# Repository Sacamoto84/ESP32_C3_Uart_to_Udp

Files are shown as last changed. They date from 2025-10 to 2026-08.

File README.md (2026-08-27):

# ESP32 UART to TCP Bridge

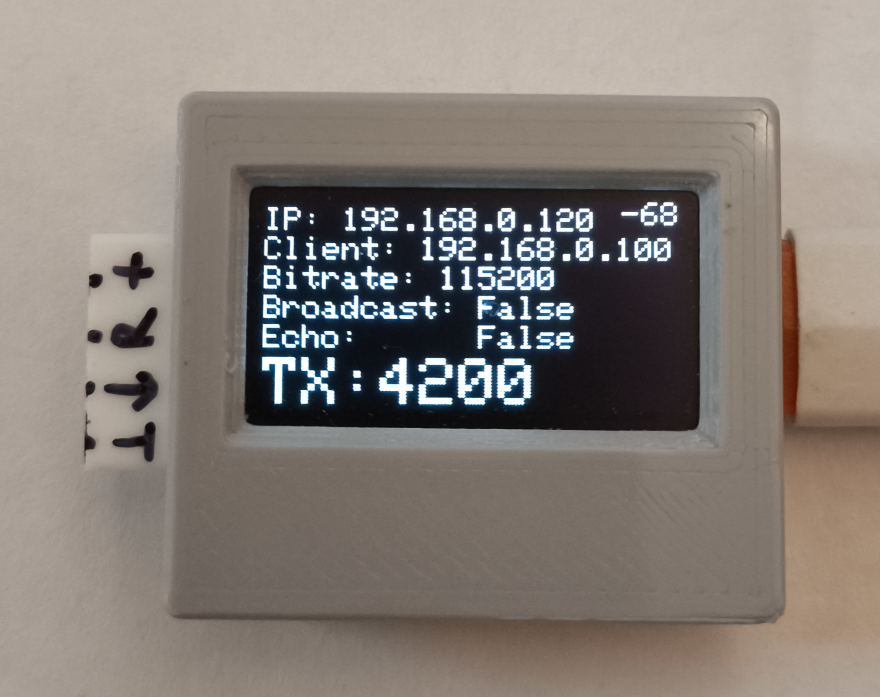
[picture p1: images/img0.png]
ESP32 UART to TCP Bridge


Прошивка превращает ESP32 в сетевой мост `UART -> TCP`, чтобы Android-приложение `TerminalM3` могло подключаться к устройству как TCP-клиент, получать поток данных из UART и показывать его в терминале.

Актуальная схема работы такая:

- ESP32 поднимает `TCP server` на порту `8888` для потока `UART -> Android`
- ESP32 поднимает `TCP server` на порту `8900` для команд `Android -> ESP32 SimpleCLI`
- Android сам подключается к ESP32 как `TCP client`
- `UDP` только для двух служебных задач:
  - heartbeat `ping/pong` на порту `8888`
  - внешний экран OLED framebuffer на порту `82`, если эта функция включена (`1024` байта для 128x64, `360` байт для 72x40)

## Что умеет проект

- Передавать поток данных из UART в TCP-соединение.
- Держать отдельную очередь `UART -> TCP`, чтобы медленная сеть не блокировала чтение UART.
- Автоматически использовать `PSRAM` под сетевую очередь, если она есть.
- Поднимать web-портал настроек на ESP32.
- Работать с `DHCP` или `static IP`.
- Публиковать сервисы через `mDNS`.
- Поддерживать `OTA`-обновление.
- Показывать локальный статус на OLED, если сборка с экраном.
- Работать в режиме точки доступа `AP ESP32`, если подключение к Wi-Fi не удалось.

## Актуальная архитектура

### 1. Передача данных UART

Основной транспорт:

```text
UART -> очередь -> TCP server:8888 -> Android TCP client
Android TCP client -> TCP server:8900 -> SimpleCLI
```

### 2. Heartbeat между Android и ESP32

Для контроля соединения используется отдельный `UDP heartbeat`.

- Android шлет на ESP32 строку вида:

```text
tm3 hb ping seq=123
```

- ESP32 отвечает обратно на IP и порт отправителя:

```text
tm3 hb pong seq=123
```

Текущие параметры по коду:

- UDP порт heartbeat: `8888`
- Android считает соединение пропавшим, если `pong` не приходит примерно `3` секунды
- в Android heartbeat сейчас запускается отдельным клиентом и используется как индикатор живого соединения

### 3. Внешний экран по UDP

Если сборка идет с экраном и в настройках включен внешний экран, ESP32 слушает UDP-порт `82` и принимает framebuffer для OLED.

Это отдельный режим и он не связан с передачей UART в Android.

## Сетевые порты и сервисы

### Порты

- `TCP 8888` - основной сервер UART -> Android
- `TCP 8900` - прием команд Android -> `SimpleCLI`
- `UDP 8888` - heartbeat `ping/pong`
- `UDP 82` - внешний экран OLED framebuffer, если включен
- `TCP 80` - web-портал настроек
- `TCP 3232` - OTA

### mDNS

ESP32 публикует:

- `http.tcp` на порту `80`

Имя хоста задается через `PROJECT_OTA_HOSTNAME`, либо берется по умолчанию:

- `esp32-c3-uart`
- `esp32-s2-uart`

## Поддерживаемые платы

## ESP32-C3

Environment в `PlatformIO`:

```text
esp32-c3-devkitm-1
esp32-c3-devkitm-1_ota
```

Пины:

- `UART TX = GPIO21`
- `UART RX = GPIO20`
- `AP_MODE_PIN = GPIO8`
- `RESET_PULSE_PIN = GPIO9`
- `LED = GPIO8`

OLED `SSD1306` подключен по `SPI`:

```text
GPIO6  -> MOSI
GPIO4  -> CLK
GPIO3  -> DC
GPIO1  -> CS
GPIO2  -> RESET
```

## ESP32-C3 OLED 72x40

Для плат `ESP32-C3 0.42 OLED` / `01Space ESP32C3 0.42 OLED` добавлены окружения:

```text
esp32-c3-oled-72x40
esp32-c3-oled-72x40_ota
```

Встроенный OLED — SSD1306-совместимый, `72x40`, I2C-адрес `0x3C`:

```text
SDA -> GPIO5
SCL -> GPIO6
```

Пины моста по умолчанию:

- `UART TX = GPIO21`
- `UART RX = GPIO20`
- `RESET_PULSE_PIN = GPIO10` (GPIO9 не используется, так как это BOOT)
- `LED = GPIO8`

Малый экран показывает тот же статус в компактном шрифте. В режиме внешнего экрана по UDP он ожидает framebuffer размером `360` байт (`72 * 40 / 8`). Для OTA укажите адрес платы при загрузке, например `platformio run -e esp32-c3-oled-72x40_ota -t upload --upload-port 192.168.1.50`.

## ESP32-S2 Mini

Environment в `PlatformIO`:

```text
lolin_s2_mini
lolin_s2_mini_ota
```

Пины:

- `UART TX = GPIO5`
- `UART RX = GPIO3`
- `RESET_PULSE_PIN = GPIO9`
- `LED = GPIO15`
- `BOOT_HIGH_PIN = GPIO36`
- `BOOT_LOW_PIN = GPIO38`

OLED `SSD1306` подключен по `I2C`:

```text
SDA   -> GPIO21
SCL   -> GPIO34
VCC   -> GPIO36
GND   -> GPIO38
ADDR  -> 0x3C
RESET -> -1
```

## Wi-Fi логика

Прошивка работает так:

- стартует в режиме `STA`
- при включенном `static IP` сначала пытается применить адрес, шлюз и маску
- мощность Wi-Fi берется из настроек
- если подключение не удалось, делает повторную попытку с мощностью `8.5 dBm`
- если снова не удалось, переключается в `AP` режим
- имя точки доступа fallback-режима: `AP ESP32`

Перед инициализацией Wi-Fi частота CPU понижается до `80 MHz`.

## Статусный светодиод

Встроенный LED платы используется как индикатор состояния. Управляется отдельной `FreeRTOS`-задачей с приоритетом выше `loopTask`, поэтому мигание не зависит от текущей работы главного цикла (обновление OLED, OTA и т.д.) и работает корректно даже на одноядерном `ESP32-S2`.

Команды приходят в задачу через очередь FreeRTOS, то есть вызов из любой пользовательской таски неблокирующий и потокобезопасный.

Состояния:

- `Off` — LED выключен (Wi-Fi не активен).
- `ConnectingToStation` — медленное мигание `~350 ms` (подключение к Wi-Fi).
- `AccessPoint` — быстрое мигание `~120 ms` (активирован fallback `AP ESP32`).
- `WaitingForClient` — LED выключен (Wi-Fi подключён, TCP-клиента нет).
- `ClientConnected` — ровно горит, пока клиент на связи. При активной передаче данных быстро мигает `~20 Hz` (как activity-LED у RJ-45), через `~120 ms` после последнего пакета возвращается в ровное свечение.

Таким образом по одному светодиоду видно:

- есть ли подключение к Wi-Fi,
- подключился ли клиент к TCP-серверу,
- идёт ли сейчас реальная передача данных.

Темп мигания активности и окно удержания настраиваются константами в `src/status_led.cpp` (`kActivityBlinkHalfMs`, `kActivityHoldMs`).

### Полярность и яркость

LED считается доступным всегда:

- `ESP32-C3` — RGB/NeoPixel на пине `8`
- `LOLIN S2 Mini` — обычный GPIO на пине `15`, по умолчанию **active HIGH**

В web-портале настраиваются включение LED, полярность `active LOW` и яркость `0..255`.
По умолчанию LED включён, яркость полная: `255`.

## Очередь UART -> TCP и PSRAM

Проект использует очередь между UART и TCP, чтобы сеть не тормозила прием данных из UART.

Один элемент очереди:

```cpp
struct NetworkTxChunk {
    uint16_t len;
    uint8_t data[NETWORK_TX_CHUNK_SIZE];
};
```

Текущее поведение:

- сначала проект пытается создать очередь в `PSRAM`
- если не получилось, пытается создать очередь во внутренней RAM
- если памяти не хватает, автоматически уменьшает длину очереди в 2 раза, пока не найдет рабочий вариант
- если очередь так и не создалась, TCP server все равно стартует, чтобы это было видно в диагностике

Текущие compile-time размеры:

- `PROJECT_NETWORK_TX_CHUNK_SIZE = 1460`

Стартовое значение TX-очереди для новой базы настроек:

- `64` чанка для `ESP32-C3`
- `256` чанков для `ESP32-S2 Mini`
- дальше размер TX-очереди меняется в web-портале и применяется после перезагрузки ESP32

Дополнительно:

- драйверный RX-буфер UART: по умолчанию `64 KB`, дальше меняется в web-портале
- локальный буфер чтения из UART: `NETWORK_TX_CHUNK_SIZE * 4`
- таймаут записи TCP: `3000 ms`

Если очередь переполняется, новые данные дропаются без краша прошивки, а в лог пишется счетчик потерь.

## Web-портал настроек

Портал настроек поднимается на ESP32 и позволяет менять:

- bitrate UART
- размер входного RX-буфера Serial/UART в KB
- SSID и пароль Wi-Fi
- включение `static IP`
- `static IP`, `gateway`, `subnet`
- `echo`
- мощность передатчика Wi-Fi
- включение встроенного LED, полярность `active LOW` и яркость
- яркость OLED, если экран есть
- включение внешнего экрана по UDP `82`, если экран есть
- перезагрузку ESP32
- аппаратный импульс сброса на внешнее устройство
- очистку базы настроек

В портале также показываются:

- текущий IP ESP32
- строка OTA вида `hostname.local:3232`
- состояние OTA auth
- режим транспорта: `TCP server`
- фактический размер очереди `UART -> TCP`

## OTA

Параметры по умолчанию:

- OTA порт: `3232`
- hostname для `ESP32-C3`: `esp32-c3-uart`
- hostname для `ESP32-S2 Mini`: `esp32-s2-uart`

Environment для OTA:

```text
esp32-c3-devkitm-1_ota
esp32-c3-oled-72x40_ota
lolin_s2_mini_ota
```

Примеры:

```bash
platformio run --environment esp32-c3-devkitm-1
platformio run --environment esp32-c3-devkitm-1_ota --target upload
platformio run --environment esp32-c3-oled-72x40
platformio run --environment esp32-c3-oled-72x40_ota --target upload --upload-port 192.168.1.50
platformio run --environment lolin_s2_mini
platformio run --environment lolin_s2_mini_ota --target upload
```

## Полезные build flags

### Без экрана SSD1306 128x64

```text
-DPROJECT_NO_SCREEN=1
```

### Размеры сетевых буферов

```text
-DPROJECT_NETWORK_TX_CHUNK_SIZE=1460
```

### Подробный лог UART hot path

Включать только для отладки, потому что заметно нагружает быстрый путь:

```text
-DPROJECT_UART_VERBOSE_LOG=1
```

### Ожидание Serial-монитора при старте

По умолчанию прошивка ждёт подключение Serial-монитора до `5000 ms`, чтобы ранние диагностические логи не терялись сразу после сброса.
Отключить ожидание или изменить таймаут можно флагом:

```text
-DPROJECT_BOOT_SERIAL_DELAY_MS=0
```

### OTA hostname и пароль

```text
-DPROJECT_OTA_HOSTNAME="my-esp32-bridge"
-DPROJECT_OTA_PASSWORD="change-me"
```

## Запуск с Android TerminalM3

- https://github.com/Sacamoto84/Android_TerminalM3

Android-приложение работает с этой прошивкой по такой схеме:

1. Android определяет IP ESP32 автоматически или берет его из ручной настройки.
2. Android открывает постоянное `TCP` соединение на `8888` для чтения UART.
3. Android шлет команды `SimpleCLI` в `TCP 8900` по схеме `connect -> send -> close`.
4. Параллельно Android шлет heartbeat `ping` по `UDP 8888`.
5. Если heartbeat пропадает, Android считает сервер потерянным, роняет TCP-сокет и пытается переподключиться.

Это позволяет отдельно контролировать жив ли сервер, даже если TCP еще не успел сам отвалиться по таймаутам ОС.

## Связанные документы

- [Корневой README проекта Android TerminalM3](../README.md)
- [README консольных виджетов Android](../app/src/main/java/com/example/terminalm3/console/README.md)
- [README библиотеки TimberWidget для Arduino/PlatformIO](../TimberWidget/README.md)

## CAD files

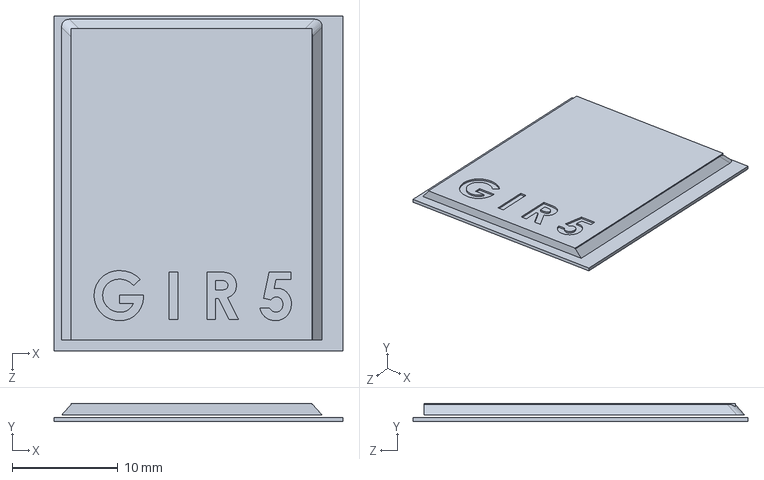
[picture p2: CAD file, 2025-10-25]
3d/крышка.SLDPRT
27.3 x 1.72 x 31.6 mm

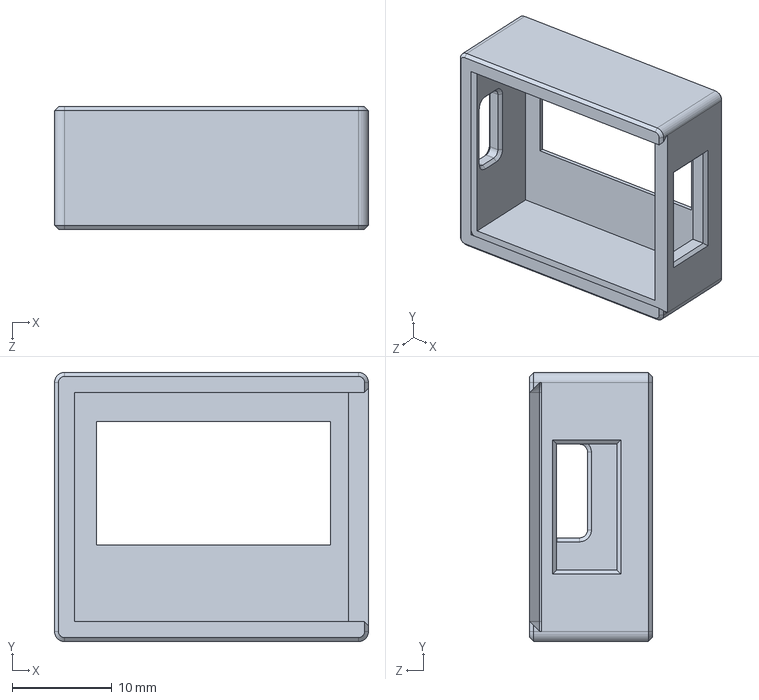
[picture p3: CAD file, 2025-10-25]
3d/низ.SLDPRT
31.5 x 27.0 x 12.3 mm

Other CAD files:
3d/крышка.STL
3d/низ.STL

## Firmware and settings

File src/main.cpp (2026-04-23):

#include "app_globals.h"

#include "display.h"
#include "network_bridge.h"

#include <GTimer.h>

// Держит главный цикл коротким: обслуживает OTA, внутренности настроек/БД,
// heartbeat-ответы и активный режим отображения.
void loop()
{
    // OTA нужно обслуживать именно в loop, иначе сессия обновления откроется,
    // но прошивка не начнёт принимать входящие данные.
    tickOTA();
    sett.tick();
    db.tick();
    handleHeartbeatUdp();

#if PROJECT_HAS_SCREEN
    // Локальный экран состояния обновляем периодически, а не на каждой итерации loop.
    static GTimer<millis> statusScreenTimer(2000, true);

    bool externalScreenEnabled = db.get(kk::externalScreen);
    if (externalScreenEnabled)
    {
        // Когда включён внешний экран, локальный OLED работает как сырой буфер кадра,
        // который обновляется входящими UDP-пакетами.
        handleExternalScreenUdp();
        return;
    }

    if (statusScreenTimer)
    {
        // Иначе показываем обычный встроенный экран состояния.
        screenLoop();
    }
#endif
}

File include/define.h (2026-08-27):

#ifndef _define_h
#define _define_h

#include <Arduino.h>
#include <WiFi.h>
#include <WiFiUdp.h>

// Для сборки без локального OLED-экрана добавьте:
// -DPROJECT_NO_SCREEN=1
#if defined(PROJECT_NO_SCREEN)
#define PROJECT_HAS_SCREEN 0
#else
#define PROJECT_HAS_SCREEN 1
#endif

#if PROJECT_HAS_SCREEN
#include <SPI.h>
#include <Wire.h>
#include <U8g2lib.h>
#endif
#include <stdlib.h>
#include <stdio.h>
#include <string.h>
#include <inttypes.h>

#include "esp32_log.h"

#include "driver/gpio.h"
#include "driver/uart.h"

#define FW_VERSION "1.7.4"

// Назначение пинов зависит от выбранного окружения PlatformIO и варианта платы.
#if defined(HW_VARIANT_ESP32_S2_MINI)
#define BOARD_LABEL "ESP32-S2 Mini"
#define SCREEN_WIDTH 128
#define SCREEN_HEIGHT 64
#define OLED_USE_I2C 1
#define OLED_SDA_PIN 21
#define OLED_SCL_PIN 34
#define OLED_I2C_ADDR 0x3C
#define OLED_RESET_PIN -1
#define UART_TX_PIN 5
#define UART_RX_PIN 3
#define BOOT_HIGH_PIN 36
#define BOOT_LOW_PIN 38
#define AP_MODE_PIN -1
#define RESET_PULSE_PIN 9
#define STATUS_LED_BOARD_PIN 15
#elif defined(HW_VARIANT_ESP32_C3)
#define BOARD_LABEL "ESP32-C3"
#define SCREEN_WIDTH 128
#define SCREEN_HEIGHT 64
#define OLED_USE_I2C 0
#define OLED_MOSI_PIN 6
#define OLED_CLK_PIN 4
#define OLED_DC_PIN 3
#define OLED_CS_PIN 1
#define OLED_RESET_PIN 2
#define UART_TX_PIN 21
#define UART_RX_PIN 20
#define BOOT_HIGH_PIN -1
#define BOOT_LOW_PIN -1
#define AP_MODE_PIN 8
#define RESET_PULSE_PIN 9
#define STATUS_LED_BOARD_PIN 8
#elif defined(HW_VARIANT_ESP32_C3_OLED_72X40)
// 01Space/ESP32-C3 SuperMini OLED: встроенный SSD1306-совместимый OLED 0.42".
#define BOARD_LABEL "ESP32-C3 OLED 72x40"
#define SCREEN_WIDTH 72
#define SCREEN_HEIGHT 40
#define OLED_USE_I2C 1
#define OLED_SDA_PIN 5
#define OLED_SCL_PIN 6
#define OLED_I2C_ADDR 0x3C
#define OLED_RESET_PIN -1
#define UART_TX_PIN 21
#define UART_RX_PIN 20
#define BOOT_HIGH_PIN -1
#define BOOT_LOW_PIN -1
#define AP_MODE_PIN -1
// GPIO9 — кнопка BOOT на этой плате, поэтому для линии reset внешнего устройства
// выбран свободный GPIO10.
#define RESET_PULSE_PIN 10
#define STATUS_LED_BOARD_PIN 8
#else
#error "Unsupported hardware variant. Add a build flag for the target board."
#endif

#if PROJECT_HAS_SCREEN
#if defined(HW_VARIANT_ESP32_C3_OLED_72X40)
using OledDisplay = U8G2_SSD1306_72X40_ER_F_HW_I2C;
#elif OLED_USE_I2C
using OledDisplay = U8G2_SSD1306_128X64_NONAME_F_HW_I2C;
#else
using OledDisplay = U8G2_SSD1306_128X64_NONAME_F_4W_HW_SPI;
#endif

#if OLED_RESET_PIN < 0
#define OLED_RESET_U8G2_PIN U8X8_PIN_NONE
#else
#define OLED_RESET_U8G2_PIN OLED_RESET_PIN
#endif
#endif

// Размер одного чанка в очереди UART->TCP.
#if defined(PROJECT_NETWORK_TX_CHUNK_SIZE)
#define NETWORK_TX_CHUNK_SIZE PROJECT_NETWORK_TX_CHUNK_SIZE
#else
#define NETWORK_TX_CHUNK_SIZE 1024
#endif

// Подробный лог по каждому UART-пакету включается флагом:
// -DPROJECT_UART_VERBOSE_LOG=1
#if defined(PROJECT_UART_VERBOSE_LOG)
#define PROJECT_UART_VERBOSE_LOG_ENABLED 1
#else
#define PROJECT_UART_VERBOSE_LOG_ENABLED 0
#endif

// Даёт время USB Serial Monitor подключиться на старте, чтобы не потерять ранние логи.
// Отключается через -DPROJECT_BOOT_SERIAL_DELAY_MS=0
#if defined(PROJECT_BOOT_SERIAL_DELAY_MS)
#define BOOT_SERIAL_DELAY_MS PROJECT_BOOT_SERIAL_DELAY_MS
#else
#define BOOT_SERIAL_DELAY_MS 5000
#endif

#define PROJECT_OTA_PORT 3232

#if defined(PROJECT_OTA_HOSTNAME)
#define PROJECT_DEVICE_HOSTNAME PROJECT_OTA_HOSTNAME
#elif defined(HW_VARIANT_ESP32_S2_MINI)
#define PROJECT_DEVICE_HOSTNAME "esp32-s2-uart"
#elif defined(HW_VARIANT_ESP32_C3)
#define PROJECT_DEVICE_HOSTNAME "esp32-c3-uart"
#else
#define PROJECT_DEVICE_HOSTNAME "esp32-uart"
#endif

#if defined(PROJECT_OTA_PASSWORD)
#define PROJECT_OTA_PASSWORD_VALUE PROJECT_OTA_PASSWORD
#else
#define PROJECT_OTA_PASSWORD_VALUE ""
#endif

#define AP_SSID "TP-Link_BC0C"
#define AP_PASS "58133514"

#endif

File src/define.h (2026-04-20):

#ifndef _define_h
#define _define_h

#include <Arduino.h>
#include <ArduinoOTA.h>

#include <SettingsGyver.h>

#include <SPI.h>
#include <Wire.h>
#include <Adafruit_GFX.h>
#include <Adafruit_SSD1306.h>
#include "mString.h"
#include <GyverDBFile.h>
#include "eeprom.h"
#include <stdlib.h>
#include <stdio.h>
#include <string.h>
#include <inttypes.h>

#include "driver/gpio.h"
#include "driver/uart.h"

#define SCREEN_WIDTH 128 // OLED display width, in pixels
#define SCREEN_HEIGHT 64 // OLED display height, in pixels

#define FW_VERSION "1.5.8"

#if defined(HW_VARIANT_ESP32_S2_MINI)
#define BOARD_LABEL "ESP32-S2 Mini"
#define OLED_USE_I2C 1
#define OLED_SDA_PIN 18
#define OLED_SCL_PIN 33
#define OLED_I2C_ADDR 0x3C
#define OLED_RESET_PIN -1
#define UART_TX_PIN 5
#define UART_RX_PIN 3
#define BOOT_HIGH_PIN 35
#define BOOT_LOW_PIN 37
#define AP_MODE_PIN -1
#define RESET_PULSE_PIN BOOT_LOW_PIN
#elif defined(HW_VARIANT_ESP32_C3)
#define BOARD_LABEL "ESP32-C3"
#define OLED_USE_I2C 0
#define OLED_MOSI_PIN 6
#define OLED_CLK_PIN 4
#define OLED_DC_PIN 3
#define OLED_CS_PIN 1
#define OLED_RESET_PIN 2
#define UART_TX_PIN 21
#define UART_RX_PIN 20
#define BOOT_HIGH_PIN -1
#define BOOT_LOW_PIN -1
#define AP_MODE_PIN 8
#define RESET_PULSE_PIN 9
#else
#error "Unsupported hardware variant. Add a build flag for the target board."
#endif

//MARK: Define
#define AP_SSID "TP-Link_BC0C"
#define AP_PASS "58133514"

extern QueueHandle_t uartQueue;
extern GyverDBFile db;
extern void uartTask(void* arg);
extern void sendUdpMessage(const char* msg, const char* ip);
extern void build(sets::Builder &b);
extern void applyDisplayBrightness(uint8_t brightness);

// Функции инициализации из setup.cpp
extern void initPins();
extern void initSerialAndFS();
extern void initDisplay();
extern void initWiFi();
extern void initSettings();
extern void initUART();
extern void initUDP();
extern void setup();

// Функция экрана
extern void screenLoop();

#endif
